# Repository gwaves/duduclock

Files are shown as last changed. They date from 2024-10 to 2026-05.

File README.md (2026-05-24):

# DuduClock (TaoTao 天气时钟)

基于 ESP32 的桌面智能天气时钟，支持实时天气、空气质量、7日预报、计时器、本地温湿度等功能。

## 功能特性

- **实时天气**：当前温度、天气状况、体感温度、风向风力、能见度、湿度
- **空气质量**：PM10、PM2.5、NO2、SO2、CO、O3 六项指标
- **7日天气预报**：未来一周天气趋势
- **本地温湿度**：DHT11 传感器实时监测
- **NTP 自动对时**：多 NTP 服务器冗余，每 58 分钟自动校准
- **太空人动画**：桌面待机动画
- **计时器**：支持开始/暂停/归零
- **主题切换**：黑白双色主题
- **WiFi 配网**：首次启动自动进入 AP 配网模式，手机扫码即可配置

## 硬件清单

| 组件 | 规格 | 说明 |
|---|---|---|
| 主控 | ESP32-C3 / ESP32-S3 | 二选一，见下方兼容性说明 |
| 显示屏 | ST7789 240x320 TFT | 2.0 寸 IPS 屏 |
| 温湿度传感器 | DHT11 | GPIO6 |
| 按键 | 轻触开关 | GPIO8，支持单击/双击/长按 |
| LED | 板载 LED | GPIO12 |

### 显示屏接线

| TFT 引脚 | ESP32 GPIO |
|---|---|
| MOSI | 3 |
| SCLK | 2 |
| CS | 7 |
| DC | 4 |
| RST  | 5 |

## 支持的开发板

本项目已适配两款开发板，通过 PlatformIO 环境切换：

| 环境 | 开发板 | 串口 |
|---|---|---|
| `esp32c3` (默认) | AirM2M CORE ESP32C3 | `/dev/ttyACM0` |
| `esp32s3` | 立创 ESP32-S3R8N8 | `/dev/ttyUSB0` |

### ESP32-S3 兼容性说明

ESP32-S3 使用 ESP-IDF 5.x，TFT_eSPI 库需要自动补丁修复 SPI 寄存器映射问题。构建时 `scripts/patch_tft_espi_s3.py` 会自动处理，无需手动干预。

## 软件依赖

- [PlatformIO](https://platformio.org/)
- 库依赖（PlatformIO 自动安装）：
  - `bblanchon/ArduinoJson@6.21.5`
  - `mathertel/OneButton@^2.6.1`
  - `bodmer/TFT_eSPI@2.5.43`
  - `arkhipenko/TaskScheduler@3.6.0`
  - `arduinozlib`

## 构建与烧录

```bash
# ESP32-C3（默认）
pio run -e esp32c3 -t upload

# ESP32-S3
pio run -e esp32s3 -t upload

# 查看串口日志
pio device monitor -e esp32c3
```

首次烧录后需进行 WiFi 配网。

## 使用说明

### 首次配网

1. 设备首次启动自动进入配网模式，屏幕显示二维码
2. 手机连接 WiFi `TaoTaoClock`
3. 浏览器访问 `192.168.1.1`，选择 WiFi 并输入密码
4. 配置成功后设备自动重启并进入时钟页面

### 按键操作

| 操作 | 当前页面 | 功能 |
|---|---|---|
| 单击 | 计时器 | 开始/暂停计时 |
| 双击 | 任意页面 | 切换页面（天气 -> 空气质量 -> 7日预报 -> 主题 -> 计时器 -> 重置 -> 天气） |
| 长按 3s | 重置页面 | 恢复出厂设置 |
| 长按 3s | 主题页面 | 切换黑白主题 |
| 长按 3s | 计时器 | 计时归零 |

### 页面说明

- **天气页面**：显示当前时间、日期、天气图标、温度、体感温度、风向、能见度、湿度，底部轮播天气信息，左上角太空人动画
- **空气质量页面**：PM10、PM2.5、NO2、SO2、CO、O3 六项指标
- **7日预报页面**：未来一周每日天气概况
- **主题页面**：长按切换黑白主题
- **计时器页面**：单击开始/暂停，长按归零
- **重置页面**：长按 3 秒恢复出厂设置（清除 WiFi 和城市配置）

## 项目结构

```
├── include/
│   └── TFT_eSPI_Setup.h      # TFT 显示配置
├── scripts/
│   └── patch_tft_espi_s3.py  # ESP32-S3 自动补丁
├── src/
│   ├── DuduClock_2.0.ino     # 主程序入口
│   ├── net.cpp/.h            # 网络相关：WiFi、HTTP、NTP、天气 API
│   ├── task.cpp/.h           # 多任务调度、定时器、按键处理
│   ├── tftUtil.cpp/.h        # TFT 显示工具函数
│   ├── preferencesUtil.cpp/.h # NVS 持久化存储
│   ├── common.h              # 全局定义、数据结构、HTML 配网页面
│   ├── font/                 # 自定义字体
│   └── img/                  # 天气图标、太空人动画帧
├── platformio.ini            # PlatformIO 配置
└── README.md
```

## 天气数据源

- [和风天气](https://www.qweather.com/) API
- 自动定位：通过公网 IP 获取所在城市
- 数据更新频率：实况天气每 8 小时，预报每 24 小时

## 许可证

MIT License

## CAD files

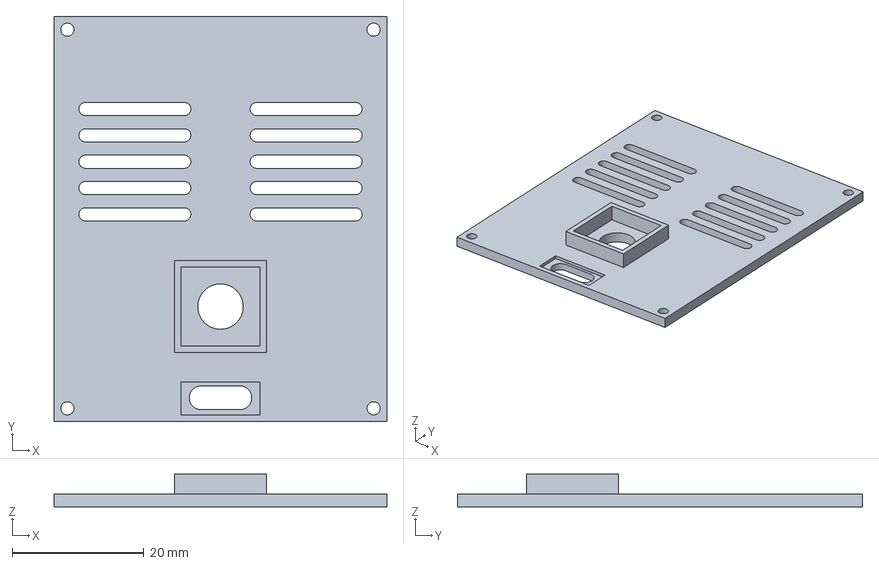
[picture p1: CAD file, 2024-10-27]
3dprint/duduclock-cover1.5.3mf
50.5 x 61.5 x 5.00 mm

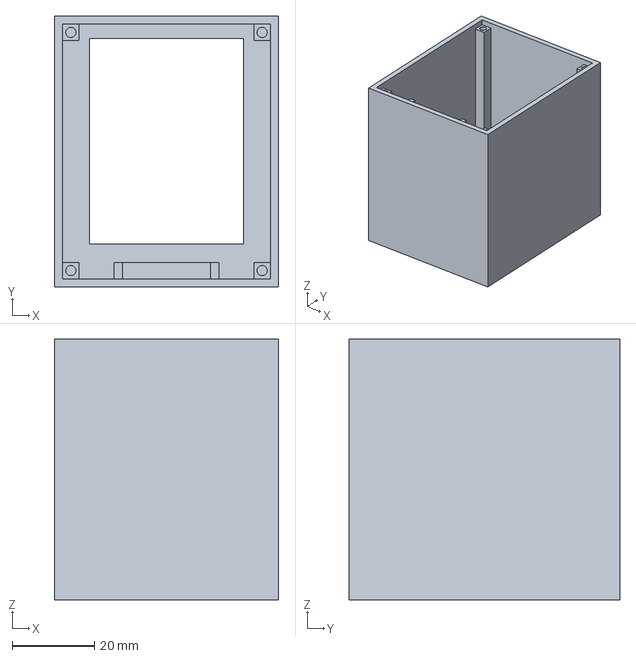
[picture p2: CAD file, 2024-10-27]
3dprint/duduclock-body1.2.3MF
54.6 x 66.0 x 63.5 mm

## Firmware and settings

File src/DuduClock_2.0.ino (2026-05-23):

#include <OneButton.h>
#include "net.h"
#include "common.h"
#include "preferencesUtil.h"
#include "tftUtil.h"
#include "task.h"

/**
TaoTao天气时钟  版本2.0

本次更新内容：

1.配网页面更新，增加了城市的上级行政区划，用于排除重名城市。
(之前输入普陀，可能是浙江舟山市普陀区，也可能是上海市普陀区，有了上级行政区划，就可以进行精确划分了)

2.更改了天气接口，由于易客天气现在只免费3个月，所以这个版本将天气接口改为了和风天气，功能更强大、接口更稳定且永久免费。

3.增加了空气质量页面，包含了pm10颗粒物，pm2.5颗粒物，no2二氧化氮，so2二氧化硫，co一氧化碳以及o3臭氧。
*/


unsigned int prevDisplay = 0; // 实况天气页面上次显示的时间
unsigned int preTimerDisplay = 0; // 计数器页面上次显示的毫秒数/10,即10毫秒显示一次
unsigned long startMillis = 0; // 开始计数时的毫秒数
int synDataRestartTime = 60; // 同步NTP时间和天气信息时，超过多少秒就重启系统，防止网络不好时，傻等
bool isCouting = false; // 计时器是否正在工作
OneButton myButton(BUTTON, true);


void setup() {
  Serial.begin(115200);
  log_v("start setup");
  int wifiInited = 0;
  // TFT初始化
  tftInit();
  
  // 显示系统启动文字
  drawText("系统启动中...");
  
  // 测试的时候，先写入WiFi信息，省的配网，生产环境请注释掉
  //setInfo4Test();
  
  // 查询是否有配置过Wifi，没有->进入Wifi配置页面（0），有->进入天气时钟页面（1）
  //getWiFiCity();
  getNvsWifi();
// nvs中没有WiFi信息，进入配置页面
  if(ssid.length() == 0 || pass.length() == 0 ){
    getNvsDefaultWifiStat();
    if(dft_wifi_exist.equals("")){
      //尝试连接默认wifi
      log_i("首次尝试连接默认wifi");
      if(connectDefaultWiFi(2)==0){
        //连接默认wifi成功，不进入配置页面，直接进入时钟页面
        currentPage = WEATHER;  
        dft_wifi_exist = "yes";    
        setNvsDefaultWifiStat();
        wifiInited = 1;
        log_i("连接默认网络成功");
      }else{
        dft_wifi_exist = "no";
        setNvsDefaultWifiStat(); 
        log_i("连接默认网络失败");
        restartSystem("连接默认网络失败,重启", true);
        
      }
    }else{ //有默认wifi信息，但是连接失败，进入配置页面
      currentPage = SETTING; // 将页面置为配置页面
      wifiConfigBySoftAP(); // 开启SoftAP配置WiFi
    }
    
  }else{ // 有WiFi信息，连接WiFi后进入时钟页面
    currentPage = WEATHER; // 将页面置为时钟页面
    // 连接WiFi,30秒超时重启并恢复出厂设置
    connectWiFi(30); 
    wifiInited = 1;
  }
  if(wifiInited == 1){  //wifi 未初始化的话，什么都不做，等配置wifi重启 
    int ret = 0;
    int retryCnt = 0;
    getNvsCity();
    log_i("city:%s",city.c_str());
    log_i("location:%s",location.c_str());
    if(city.equals("")){
      ret = getMyPubIP();
      while(ret != 0 && retryCnt < 3){
        ret = getMyPubIP();
        if(ret == 0){
          retryCnt = 0;
          break;
        }
        retryCnt++;
      }
      if(ret != 0 && retryCnt >= 3){
        restartSystem("获取公网IP失败", true);
      }

      retryCnt = 0;
      ret = getMyGeo();
      while(ret != 0 && retryCnt < 3){
        ret = getMyGeo();
        if(ret == 0){
          retryCnt = 0;
          break;
        }
        retryCnt++;
      }
      if (ret != 0 && retryCnt >= 3)
      {
        restartSystem("获取城市信息失败", true);
      }
      
      // 查询是否有城市id，如果没有，就利用city和adm查询出城市id，并保存为location
      if(location.equals("")){
        getCityID();
      }
    }

    // 初始化一些列数据:NTP对时、实况天气、一周天气
    initDatas();
    tGetLocalTempCallback();//初始化本地温湿度
    // 绘制实况天气页面
    drawWeatherPage();
    // 多任务启动
    startRunner();
    // 初始化定时器，让查询天气的多线程任务在一小时后再使能
    startTimerQueryWeather();
    // 初始化按键监控
    myButton.attachClick(click);
    myButton.attachDoubleClick(doubleclick);
    myButton.attachLongPressStart(longclick);
    myButton.setPressMs(3000); //设置长按时间为3秒，与界面提示一致
    myButton.setClickMs(600);  //设置单击判定时间为600ms，使双击更容易触发
    myButton.setDebounceMs(50); //设置消抖时长为50ms 
    
  }
  
}

void loop() {
  myButton.tick();
  drawTipsIfNeeded();
  switch(currentPage){
    case SETTING:  // 配置页面
      doClient(); // 监听客户端配网请求
      break;
    case WEATHER:  // 天气时钟页面
      executeRunner();
      time_t now;
      time(&now);
      if(now != prevDisplay){ // 每秒更新一次时间显示
        prevDisplay = now;
        // 绘制时间、日期、星期
        drawDateWeek();
      }
      break;
    case AIR:  // 空气质量页面
      executeRunner();
      break;
    case FUTUREWEATHER:  // 未来天气页面
      executeRunner();
      break;
    case THEME:  // 黑白主题设置页面
      executeRunner();
      break;
    case TIMER:  // 计时器页面
      if(isCouting && (millis() / 10) != preTimerDisplay){ // 每十毫秒更新一次数字显示
        preTimerDisplay = millis() / 10;
        // 绘制计数器数字
        drawNumsByCount(timerCount + millis() - startMillis);
      }
      break;
/*
    case ALARM:  // 闹钟页面
      executeRunner();
      break;
*/
    case RESET:  // 恢复出厂设置页面
      executeRunner();
      break;
    default:
      break;
  }
}

////////////////////////// 按键区///////////////////////
// 单击操作，用来切换各个页面
void click(){
  if(currentPage == TIMER){
    if(!isCouting){
      startMillis = millis();
    }else{
      timerCount += millis() - startMillis;
      // 绘制计数器数字
      drawNumsByCount(timerCount);
    }
    isCouting = !isCouting;
  }
}
void doubleclick(){
  switch(currentPage){
    case WEATHER:
      disableAnimScrollText();
      drawAirPage();
      currentPage = AIR;
      break;
    case AIR:
      drawFutureWeatherPage();
      currentPage = FUTUREWEATHER;
      break;
    case FUTUREWEATHER:
      drawThemePage();
      currentPage = THEME;
      break;
    case THEME:
      drawTimerPage();
      currentPage = TIMER;
      break;
    case TIMER:
      drawResetPage();
      currentPage = RESET;
      break;
    case RESET:
      drawWeatherPage();
      enableAnimScrollText();
      currentPage = WEATHER;
      break;
    default:
      break;
  }
}


void longclick(){
  if(currentPage == RESET){
    Serial.println("恢复出厂设置");
    // 恢复出厂设置并重启
    clearWiFiCity();
    restartSystem("已恢复出厂设置", false);
  }else if(currentPage == THEME){
    Serial.println("更改主题");
    if(backColor == BACK_BLACK){ // 原先为黑色主题，改为白色
      backColor = BACK_WHITE;
      backFillColor = 0xFFFF;
      penColor = 0x0000;
    }else{
      backColor = BACK_BLACK;
      backFillColor = 0x0000;
      penColor = 0xFFFF;
    }
    // 将新的主题存入nvs
    setBackColor(backColor);
    // 返回实时天气页面
    drawWeatherPage();
    enableAnimScrollText();
    currentPage = WEATHER;
  }else if(currentPage == TIMER){
    Serial.println("计数器归零");
    timerCount = 0; // 计数值归零
    isCouting = false; // 计数器标志位置为false
    drawNumsByCount(timerCount); // 重新绘制计数区域，提示区域不用变
  }

}
////////////////////////////////////////////////////////


// 初始化一些列数据:NTP对时、实况天气、一周天气
void initDatas(){
  uint8_t err_cnt=0;
  startTimerShowTips(); // 获取数据时，循环显示提示文字
  // 记录此时的时间，在同步数据时，超过一定的时间，就直接重启
  time_t start;
  time(&start);
  // 获取NTP并同步至RTC,第一次同步失败，就一直尝试同步
  getNTPTime();
  struct tm timeinfo;
  while (!getLocalTime(&timeinfo)){
    drawTipsIfNeeded();
    time_t end;
    time(&end);
    if((end - start) > synDataRestartTime){
      restartSystem("同步数据失败", true);
    }
    Serial.println("时钟对时失败...");
    getNTPTime();
  }
  //第一次查询实况天气,如果查询失败，就一直反复查询
  getNowWeather();
  while(!queryNowWeatherSuccess){
    drawTipsIfNeeded();
    time_t end;
    time(&end);
    if((end - start) > synDataRestartTime){
      restartSystem("同步当前天气数据失败", true);
    }
    err_cnt++;
    if(err_cnt > 3) { // 错误超过三次退出。
      delay(1000);
      restartSystem("同步数据失败", true);
    }
    Serial.println("实况天气查询失败...重试中...");
    delay(1000);
    getNowWeather();
  }
  log_i("实况天气查询成功");
  //第一次查询空气质量,如果查询失败，就一直反复查询
  err_cnt = 0;
  getAir();
  while(!queryAirSuccess){
    drawTipsIfNeeded();
    time_t end;
    time(&end);
    if((end - start) > synDataRestartTime){
      restartSystem("查询空气质量失败", true);
    }
    err_cnt++;
    if(err_cnt > 3) { // 错误超过三次退出。
      delay(1000);
      restartSystem("查询空气质量失败", true);
    }
    delay(1000);
    getAir();
  }
  log_i("空气质量查询成功");
  //第一次查询一周天气,如果查询失败，就一直反复查询
  err_cnt = 0;
  getFutureWeather();
  while(!queryFutureWeatherSuccess){
    drawTipsIfNeeded();
    time_t end;
    time(&end);
    if((end - start) > synDataRestartTime){
      restartSystem("同步数据失败", true);
    }
    err_cnt++;
    if(err_cnt > 3) { // 错误超过三次退出。
      delay(1000);
      restartSystem("查询未来天气失败", true);
    }
    delay(1000);
    getFutureWeather();
  }
  log_i("一周天气查询成功");
  //结束循环显示提示文字的定时器
  timerEnd(timerShowTips);
  timerShowTips = NULL;
  gTipsNeedUpdate = false; // 清除可能残留的定时器中断标志，防止启动后tips覆盖主界面
  //将isStartQuery置为false,告诉系统，启动时查询天气已完成
  isStartQuery = false;
}

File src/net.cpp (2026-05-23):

#include <HTTPClient.h>
#include <WiFi.h>
#include <WebServer.h>
#include <ArduinoJson.h>
#include <esp32-hal-log.h>
#include "ArduinoZlib.h"
#include "common.h"
#include "preferencesUtil.h"
#include "tftUtil.h"
#include "task.h"
#include "Arduino.h"

#define HTTP_BUFF_SIZE 2048

void sendNTPpacket(IPAddress &address);
void startAP();
void startServer();
void scanWiFi();
void handleNotFound();
void handleRoot();
void handleConfigWifi();
void restartSystem(String msg, bool endTips);
String urlEncode(const String& text);

bool queryNowWeatherSuccess = false;
bool queryFutureWeatherSuccess = false;
bool queryAirSuccess = false;

// Wifi相关
String ssid;  //WIFI名称
String pass;  //WIFI密码
String city;  // 城市
String adm; // 上级城市区划
String location; // 城市ID
String WifiNames; // 根据搜索到的wifi生成的option字符串
String dft_wifi_exist; // 默认wifi是否存在NULL,or "yes" or "no"
String myPubIP;
// SoftAP相关
const char *APssid = "TaoTaoClock";
IPAddress staticIP(192, 168, 1, 1);
IPAddress gateway(192, 168, 1, 254);
IPAddress subnet(255, 255, 255, 0);
WebServer server(80);
// 查询天气超时时间(ms)
int queryTimeout = 6000;
// 是否是刚启动时查询天气
bool isStartQuery = true; 
// 天气接口相关

// 开启SoftAP进行配网
void wifiConfigBySoftAP(){
  // 开启AP模式，如果开启失败，重启系统
  startAP();
  // 扫描WiFi,并将扫描到的WiFi组成option选项字符串
  scanWiFi();
  // 启动服务器
  startServer();
  // 显示配置网络页面
  tft.pushImage(0, 0, 240, 320, QRcode);
}

// 处理服务器请求
void doClient(){
  server.handleClient();
}
// 处理404情况的函数'handleNotFound'
void handleNotFound(){
  handleRoot();//访问不存在目录则返回配置页面
}
// 处理网站根目录的访问请求
void handleRoot(){
  server.send(200,"text/html", ROOT_HTML_PAGE1 + WifiNames + ROOT_HTML_PAGE2);
}
// 提交数据后的提示页面
void handleConfigWifi(){
  //判断是否有WiFi名称
  if (server.hasArg("ssid")){
    log_i("获得WiFi名称: %s",server.arg("ssid").c_str());
    ssid = server.arg("ssid");
  }else{
    log_e("错误, 没有发现WiFi名称");
    server.send(200, "text/html", "<meta charset='UTF-8'>错误, 没有发现WiFi名称");
    return;
  }
  //判断是否有WiFi密码
  if (server.hasArg("pass")){
    log_i("获得WiFi密码:%s",server.arg("pass").c_str());
    pass = server.arg("pass");    
  }else{
    log_e("错误, 没有发现WiFi密码");
    server.send(200, "text/html", "<meta charset='UTF-8'>错误, 没有发现WiFi密码");
    return;
  }
  // 将信息存入nvs中
  setNvsWifi();
  // 获得了所需要的一切信息，给客户端回复
  server.send(200, "text/html", "<meta charset='UTF-8'><style type='text/css'>body {font-size: 2rem;}</style><br/><br/>WiFi: " + ssid + "<br/>密码: " + pass + "<br/>已取得相关信息,正在尝试连接,请手动关闭此页面。");
  restartSystem("即将尝试连接", false);
}
//尝试连接默认的wifi，如果失败，返回，并进入正常wifi获取流程
int connectDefaultWiFi(int timeOut_s){
  delay(1500); // 让“系统启动中”字样多显示一会
  drawText("正在连接默认网络...");
  log_i("正在连接默认网络,wifi stutas:%d",WiFi.status());
  int connectTime = 0; //用于连接计时，如果长时间连接不成功，复位设备
  pinMode(D4,OUTPUT);
  ssid = "tommy-home";
  log_i("正在连接网络%s",ssid.c_str());
  pass = "tommy-ssid";
  
  WiFi.begin(ssid, pass);
  while (WiFi.status() != WL_CONNECTED) {
    log_printf(".");
    digitalWrite(D4, !digitalRead(D4));
    delay(500);
    connectTime++;
    if (connectTime > 2 * timeOut_s){ //长时间连接不上，清除nvs中保存的网络数据，并重启系统
      log_e("网络连接失败");
      ssid = "";
      pass = "";
      return -1;
    }
    
  }
  digitalWrite(D4, LOW); // 连接成功后，将D4指示灯熄灭
  setNvsWifi(); // 将信息存入nvs中  
  log_i("网络连接成功");
  log_i("本地IP: %d.%d.%d.%d",WiFi.localIP()[0],WiFi.localIP()[1],WiFi.localIP()[2],WiFi.localIP()[3]);
  return 0;
}
// 连接WiFi
void connectWiFi(int timeOut_s){
  delay(1500); // 让“系统启动中”字样多显示一会
  drawText("正在连接网络...");
  int connectTime = 0; //用于连接计时，如果长时间连接不成功，复位设备
  pinMode(D4,OUTPUT);
  log_i("正在连接网络");
  log_i("%s",ssid.c_str());
  
  WiFi.begin(ssid, pass);
  while (WiFi.status() != WL_CONNECTED) {
    Serial.print(".");
    digitalWrite(D4, !digitalRead(D4));
    delay(500);
    connectTime++;
    if (connectTime > 2 * timeOut_s){ //长时间连接不上，清除nvs中保存的网络数据，并重启系统
      log_e("网络连接失败");
      clearNvsWifi();
      restartSystem("网络连接失败", false);
    }
  }
  digitalWrite(D4, LOW); // 连接成功后，将D4指示灯熄灭
  log_i("网络连接成功");
}
// 检查WiFi连接状态，如果断开了，重新连接
void checkWiFiStatus(){
  wl_status_t status = WiFi.status();
  if(status == WL_DISCONNECTED || status == WL_NO_SSID_AVAIL || status == WL_CONNECT_FAILED || status == WL_CONNECTION_LOST){
    log_e("网络断开，即将重新连接...");
    WiFi.begin(ssid, pass);
  }
}
// 启动服务器
void startServer(){
  // 当浏览器请求服务器根目录(网站首页)时调用自定义函数handleRoot处理，设置主页回调函数，必须添加第二个参数HTTP_GET，否则无法强制门户
  server.on("/", HTTP_GET, handleRoot);
  // 当浏览器请求服务器/configwifi(表单字段)目录时调用自定义函数handleConfigWifi处理
  server.on("/configwifi", HTTP_POST, handleConfigWifi);
  // 当浏览器请求的网络资源无法在服务器找到时调用自定义函数handleNotFound处理   
  server.onNotFound(handleNotFound);
  server.begin();
  log_i("服务器启动成功！");
}
// 开启AP模式，如果开启失败，重启系统
void startAP(){
  log_i("开启AP模式...");
  WiFi.enableAP(true); // 使能AP模式
  //传入参数静态IP地址,网关,掩码
  WiFi.softAPConfig(staticIP, gateway, subnet);
  if (!WiFi.softAP(APssid)) {
    log_e("AP模式启动失败");
    ESP.restart(); // Ap模式启动失败，重启系统
  }  
  log_i("AP模式启动成功");
  log_i("IP地址:%s ",WiFi.softAPIP().toString().c_str());
  
}
// 扫描WiFi,并将扫描到的Wifi组成option选项字符串
void scanWiFi(){
  log_i("开始扫描WiFi");
  int n = WiFi.scanNetworks();
  if (n>=0 && n<=64){
    log_i("扫描到%d个WIFI",n);
    
    WifiNames = "";
    for (size_t i = 0; i < n; i++){
      int32_t rssi = WiFi.RSSI(i);
      String signalStrength;
      if(rssi >= -35){
        signalStrength = " (信号极强)";
      }else if(rssi >= -50){
        signalStrength = " (信号强)";
      }else if(rssi >= -70){
        signalStrength = " (信号中)";
      }else{
        signalStrength = " (信号弱)";
      }
      WifiNames += "<option value='" + WiFi.SSID(i) + "'>" + WiFi.SSID(i) + signalStrength + "</option>";
      Serial.print("WiFi的名称(SSID):");
      Serial.println(WiFi.SSID(i));
    }
  }else{
    log_e("WIFI数量异常：%d",n);
    delay(1000);
    // 不直接重启，让调用者处理异常
  }
}

//查询我的公网地址
int getMyPubIP(){
  HTTPClient http;
  http.setConnectTimeout(queryTimeout);
  http.begin(myipURL);
  log_i("start to get my public IP:%s",myipURL.c_str());
  int httpCode = http.GET();
  if (httpCode== HTTP_CODE_OK)
  {
    /* code */
    String payload = http.getString();
    log_d("%s",payload);
    //解析json数据
    StaticJsonDocument<64> doc;//小请求，用静态分配
    DeserializationError error = deserializeJson(doc, payload); //反序列化JSON数据
    if(!error){ //检查反序列化是否成功
      myPubIP = doc["ip"].as<const char*>();
      log_i("我的IP地址: %s",myPubIP.c_str());
    }
    else{
      log_e("解析json数据失败");
      http.end();
      return -1;
    }
  }
  else{
    log_e("获取IP地址错误：");
    log_e("HTTP Code: %d", httpCode);
    log_e("IP地址错误，即将重启系统");
    http.end();
    return -1;
    
  }
  http.end();
  return 0;
}
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

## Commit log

2024-10-27 Update preferencesUtil.cpp add beijing location; DuduClock_2.0.ino 打开默认setinfo； net.cpp 把几个http相关的请求处理中的栈数据改用动态堆数据。
2024-10-27 增加重新设计的3d打印外壳文件，相比原始版本，增加了esp32开发板的卡槽高度，增加了外壳厚度，做了部分安装便捷性修改。
    [duduclock-body1.2.3MF, duduclock-cover1.5.3mf]
2024-10-27 增加platformio添加的依赖，以便于后续直接编译。
2024-10-28 增加闹钟的初步代码，后续继续
2024-10-30 修正本地温度采集显示刷新问题，增加闹钟数据的nvs保存。
2024-10-31 更新本地温度显示刷新的逻辑，每次本地温度更新后，强制刷新一次温度显示
2024-11-03 蜂鸣器效果太差，放弃闹铃功能
2024-11-03 删除残余闹钟代码，修改液晶屏的rgb顺序定义。
2024-11-03 默认DHT11 pin 6
2024-11-06 增加了通过http api获取当前ip地址以及查询城市信息的代码，从而避免在wifi配置时关于行政区划的配置迷糊
2024-11-09 不再需要wifi配置时填写城市信息。优化wifi配置以及城市信息获取的代码安全性。
2024-11-09 修改默认log level，修正log类型
2024-11-30 修改初始化网络逻辑
2024-12-01 修正获取本地location逻辑
2024-12-01 修正了默认wifi的初始化过程
2025-01-01 修改API查询粒度
2025-01-02 修正本地温度显示的bug
2026-05-23 修复启动崩溃与空气质量查询失败
    1. 修复getAir/getNowWeather中log_e的格式符错误(%s→%d)，
    避免将int类型的httpCode当指针解引用导致Load access fault崩溃
    2. 为getAir添加JSON过滤器，只提取now节点下的字段，
    避免大量station数据撑爆2048字节内存导致NoMemory
    3. getMyGeo改用ipinfo.io获取地理位置，更稳定
    4. getCityID增加空城市检查、数据流异常大小校验
    5. 修复头文件大小写(PreferencesUtil→preferencesUtil)
    6. platformio.ini upload_port适配Linux串口
    [DuduClock_2.0.ino, net.cpp]
2026-05-23 修复代码审查中发现的所有问题
    - net.cpp:
    - 消除全局HTTPClient，改为局部实例，避免多任务竞争
    - 所有HTTP函数确保每个return路径都释放内存和关闭连接
    - getAir()增加JSON过滤器，避免大JSON导致NoMemory
    - getMyGeo()改用HTTPS (ipinfo.io)
    - checkWiFiStatus()增加WL_NO_SSID_AVAIL等状态判断
    - scanWiFi()异常时不再直接重启
    - 修正libmpq__decompress_zlib流式解压：移除错误的break，444是正常中间状态
    - DuduClock_2.0.ino:
    - sleep(1)改为delay(1000)
    - timerShowTips结束后置NULL
    - 阻塞循环中增加drawTipsIfNeeded()刷新提示文字
    - task.cpp/task.h:
    - 将TFT绘制移出IRAM_ATTR定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
    [DuduClock_2.0.ino, net.cpp, task.cpp]
2026-05-23 修复双击按键切换页面不灵敏的问题
    - 将消抖时间从10ms恢复到50ms，避免机械按键弹跳造成误判
    - 增加单击判定时间到600ms（默认400ms），给双击留出更宽松的触发窗口
    - 将长按时间从2000ms修正为3000ms，与界面提示文字"长按3秒"保持一致
    [DuduClock_2.0.ino]
2026-05-23 修复轮播阻塞、DHT重绘、清理死代码
    - task.cpp:
    - tScrollTextCallback 改为非阻塞触发器，新增 tScrollAnim 逐帧动画任务
    - DHT11 读取后不再重绘整页，改为仅刷新温湿度数字区域
    - 删除 drawTHProgressBar 中被注释掉的进度条死代码
    - 清理大量注释掉的 Serial.println、旧变量定义、死循环等废弃代码
    - 修正 log_v(data.c_str()) 为 log_v("%s", data.c_str())
    - 清理注释掉的 sing_a_song、Serial.println 等死代码
    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
    [DuduClock_2.0.ino, net.cpp, task.cpp]
2026-05-23 修复启动后第一屏显示异常的问题
    initDatas() 结束定时器后，可能仍有挂起的中断导致 gTipsNeedUpdate
    被置位。loop() 首次执行时 drawTipsIfNeeded() 会把提示文字绘制在
    天气页面上方，覆盖标题和城市信息。在 timerEnd() 后清除标志位，
    防止提示文字残留。
    [DuduClock_2.0.ino]
2026-05-23 支持 ESP32-C3 和 ESP32-S3 双板兼容
    - platformio.ini: 添加 esp32s3 环境配置，保留 esp32c3 为默认
    - include/TFT_eSPI_Setup.h: 提取 TFT 显示配置为独立头文件
    - scripts/patch_tft_espi_s3.py: 构建前自动修补 TFT_eSPI 的 SPI_PORT
    定义，解决 ESP-IDF 5.x 下 SPI2_HOST 枚举值变更导致的 StoreProhibited 崩溃
    - src/task.cpp: timerAttachInterrupt 统一使用 LEVEL 模式（ESP32-S3 不支持 EDGE）
2026-05-24 修复 ESP32-C3 白屏与温湿度重绘重叠问题，添加 Kimi 联网搜索工具
    - include/TFT_eSPI_Setup.h: 添加 USER_SETUP_LOADED 防止默认 ILI9341 配置冲突
    - src/task.cpp: 在 drawTHProgressBar() 中清除整个温湿度文字区域，
    避免数字位数或正负号变化时产生残影；移除 drawWeatherContent() 中
    仅覆盖右侧的局部 sprite 清理
    - TFT_eSPI ESP32_C3 处理器: SPI_PORT 硬编码为 2（ESP-IDF 5.x 中
    SPI2_HOST 枚举值变为 1，导致 SPI 寄存器基址计算错误，引发白屏）
    - 恢复 SPI 寄存器宏使用 SPI_USER_REG(SPI_PORT)，因 SPI_PORT 已正确固定
    - 添加 tools/kimi_web_search.py 联网搜索示例工具
    - 添加 RE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
    [TFT_eSPI_Setup.h, task.cpp]
2026-05-24 添加 ESP32-C3 TFT_eSPI 自动 patch 脚本
    - scripts/patch_tft_espi_c3.py: build 前自动修复 ESP-IDF 5.x 兼容性问题
    - SPI_PORT 硬编码为 2（SPI2_HOST 枚举值在 ESP-IDF 5.x 变为 1）
    - _spi_user 从硬编码地址改回 SPI_USER_REG(SPI_PORT)
    - 自动添加 hal/gpio_ll.h 头文件
    - platformio.ini: esp32c3 环境注册 pre-build patch 脚本
